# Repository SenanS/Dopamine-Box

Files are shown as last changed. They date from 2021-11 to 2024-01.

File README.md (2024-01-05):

# Dopamine-Box
## Blog post about the [Dopamine box here](https://senans.github.io/Technical-Blog/2023/10/04/Dopamine-Box/)

A flip switch circuit for encouraging you to complete tasks, loaded with lights and achievement sounds.

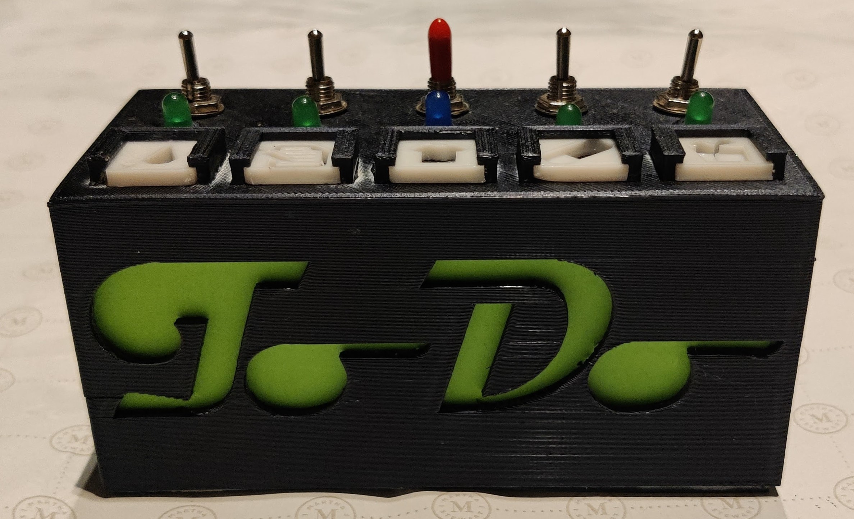
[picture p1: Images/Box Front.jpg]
The Dopamine Box


This project was conceptualized and designed by me, to gamify mundane tasks. It tracks up to five tasks, offering audiovisual feedback upon completion of each task, effectively rewarding the user with a dopamine hit.

[Board Schema](Schema.pdf) | [Stripboard Schema](Stripboard.pdf)
:-------------------------:|:-------------------------:
Schema | Stripboard

This project was more than just a tool for self-motivation; I used it as a springboard to dive into the realms of audio amplifiers and probability distributions.

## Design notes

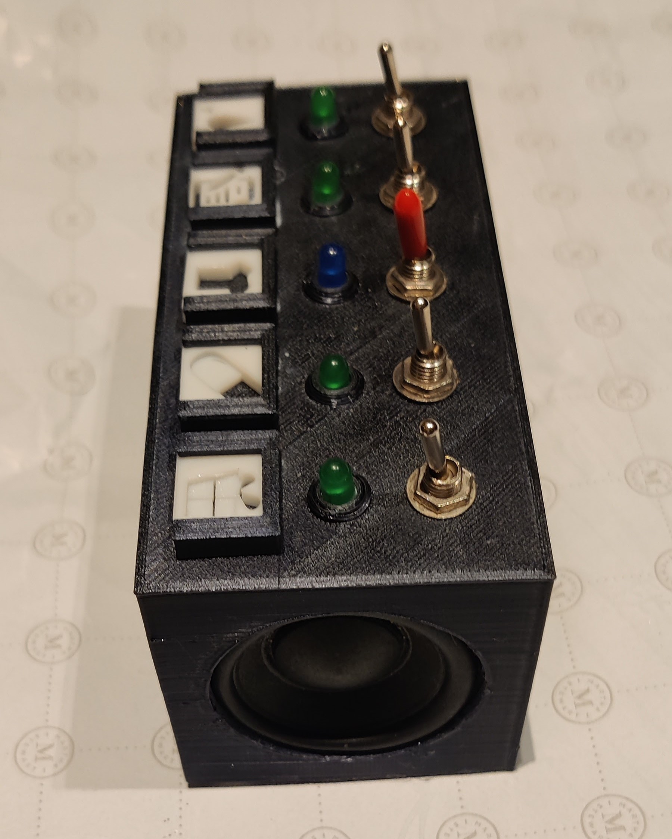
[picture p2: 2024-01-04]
Images/Box Side.jpg

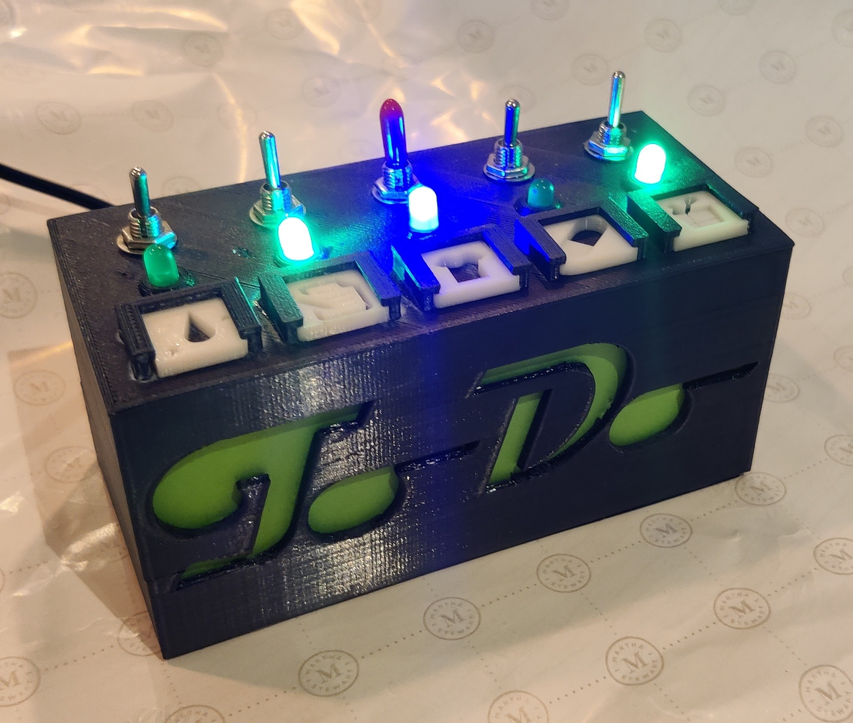
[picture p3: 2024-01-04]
Images/Box Lit.jpg

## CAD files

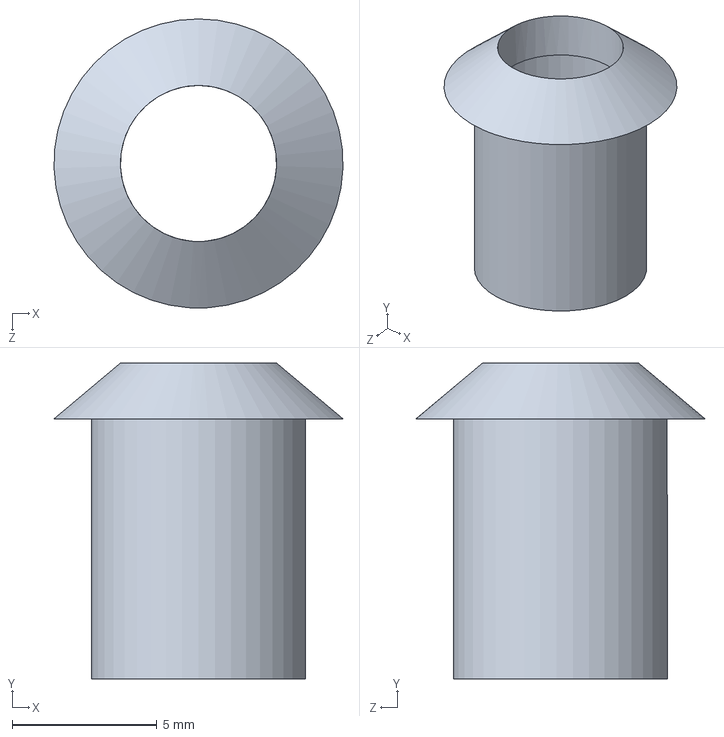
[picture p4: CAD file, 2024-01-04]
3D Models/LEDHolder.SLDPRT
9.99 x 10.9 x 10.0 mm

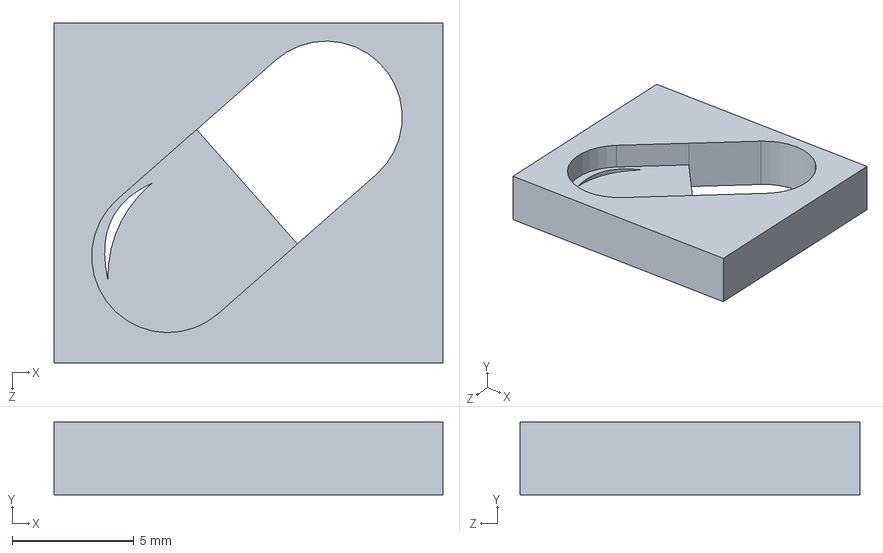
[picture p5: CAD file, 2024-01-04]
3D Models/Tokens/pill.SLDPRT
16.0 x 3.00 x 14.0 mm

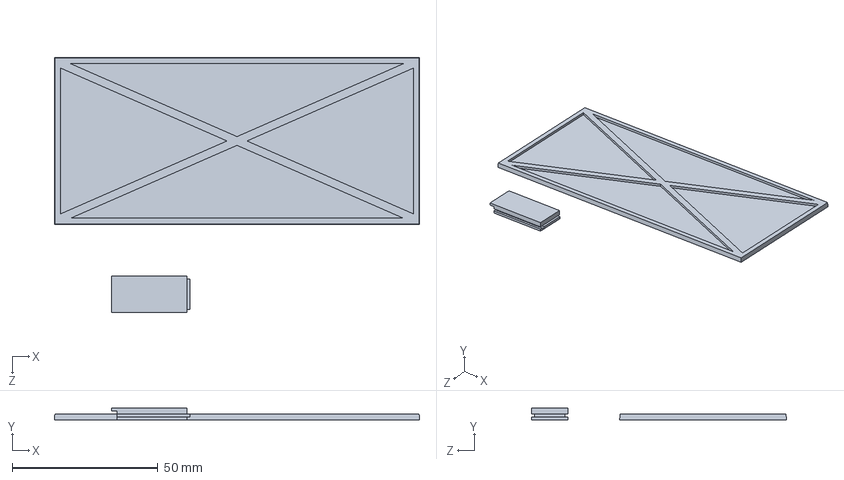
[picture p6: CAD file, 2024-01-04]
3D Models/Part2.SLDPRT
125.2 x 4.00 x 87.4 mm

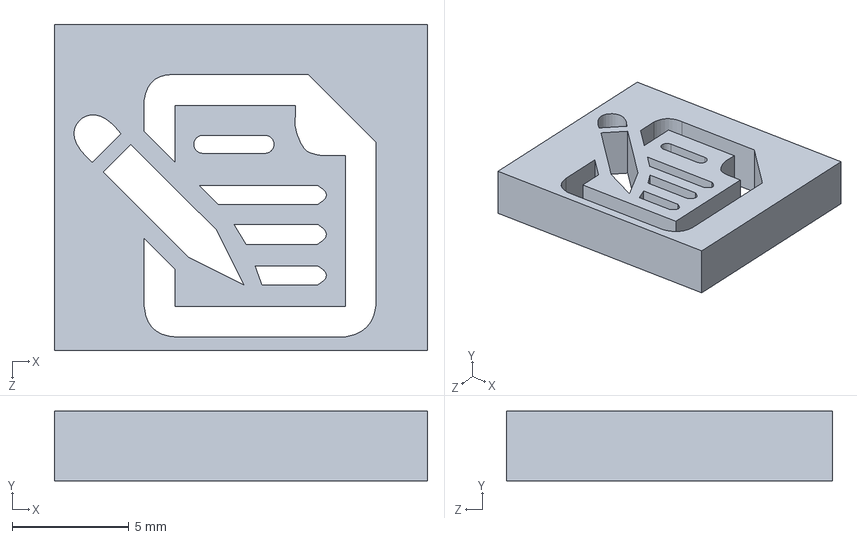
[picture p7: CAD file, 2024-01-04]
3D Models/Tokens/bits.SLDPRT
16.0 x 3.00 x 14.0 mm

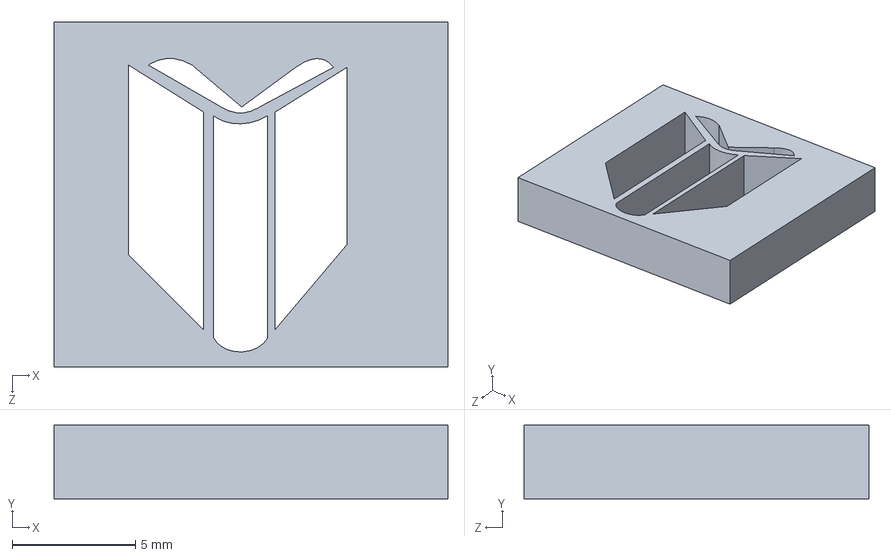
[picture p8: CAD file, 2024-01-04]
3D Models/Tokens/book.SLDPRT
16.0 x 3.00 x 14.0 mm

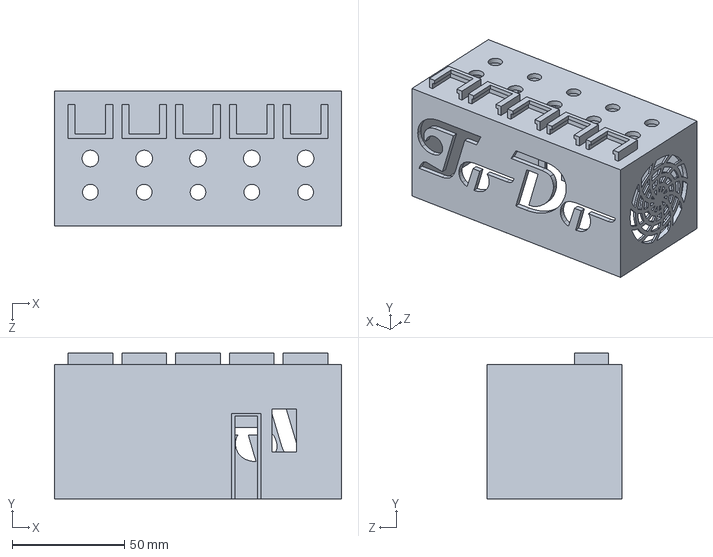
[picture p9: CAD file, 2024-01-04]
3D Models/Part1.SLDPRT
128.0 x 65.0 x 60.0 mm

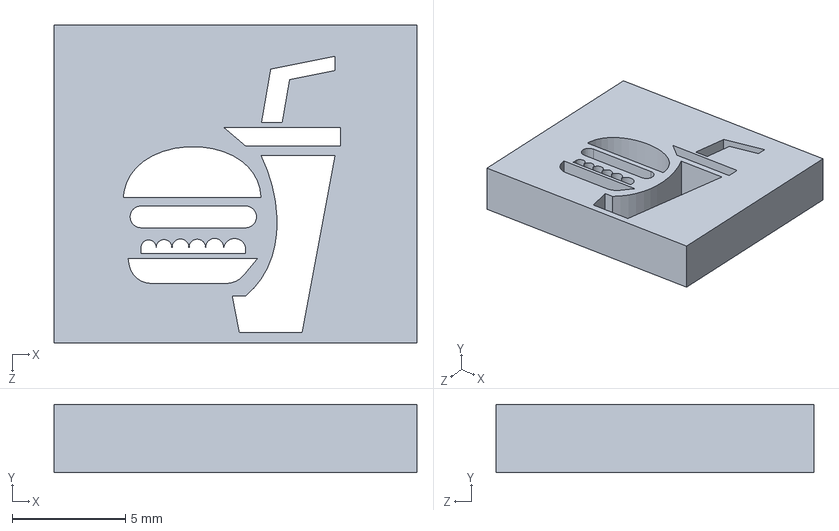
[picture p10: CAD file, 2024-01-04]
3D Models/Tokens/food.SLDPRT
16.0 x 3.00 x 14.0 mm

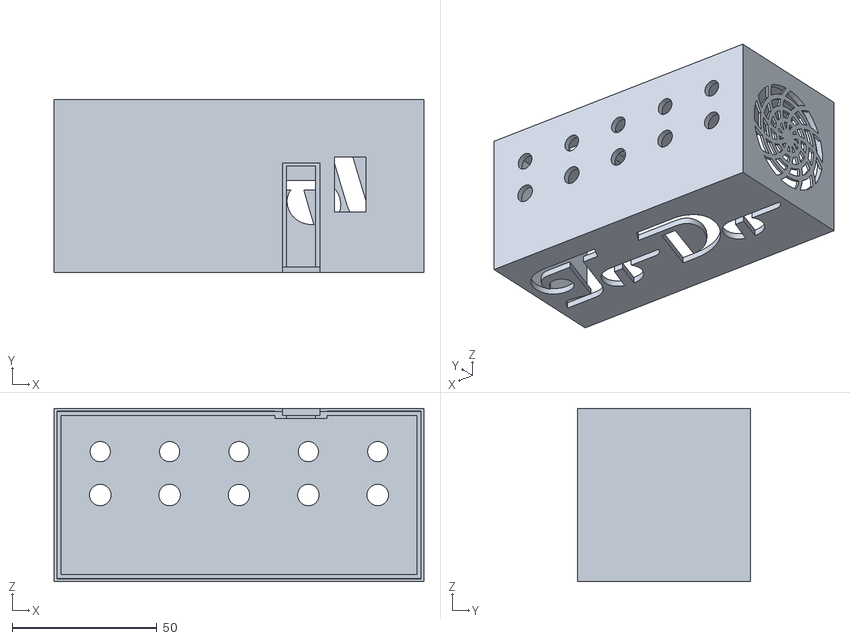
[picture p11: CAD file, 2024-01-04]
3D Models/dopbody.STL
128.0 x 60.0 x 60.0

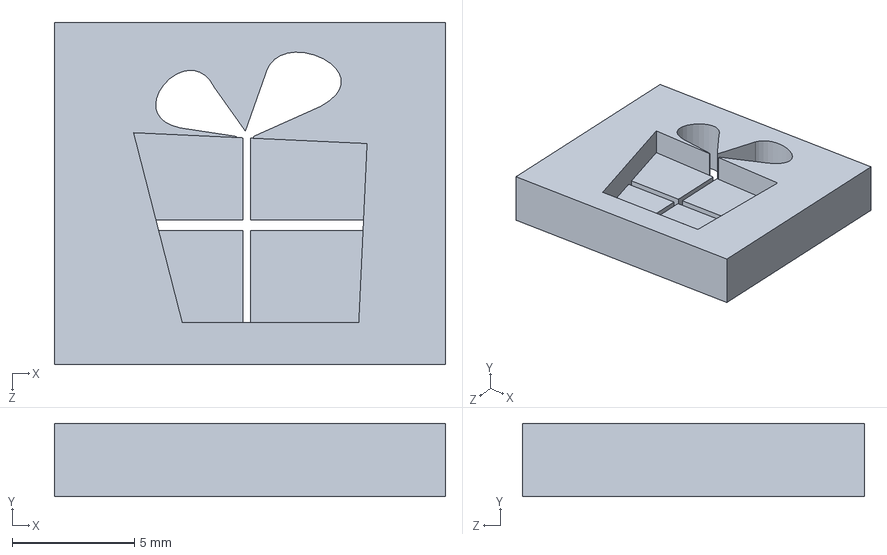
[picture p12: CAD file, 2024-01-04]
3D Models/Tokens/pressie.SLDPRT
16.0 x 3.00 x 14.0 mm

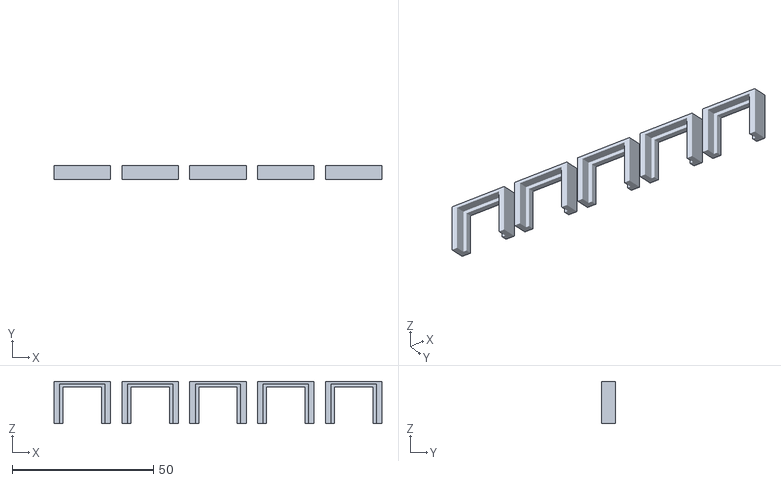
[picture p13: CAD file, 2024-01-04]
3D Models/dopHang.STL
116.0 x 5.00 x 15.0

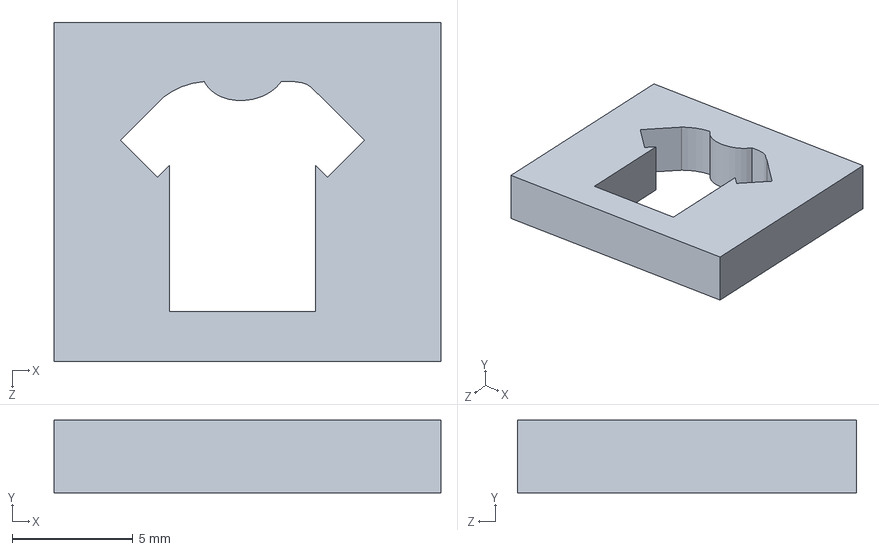
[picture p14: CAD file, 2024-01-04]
3D Models/Tokens/top.SLDPRT
16.0 x 3.00 x 14.0 mm

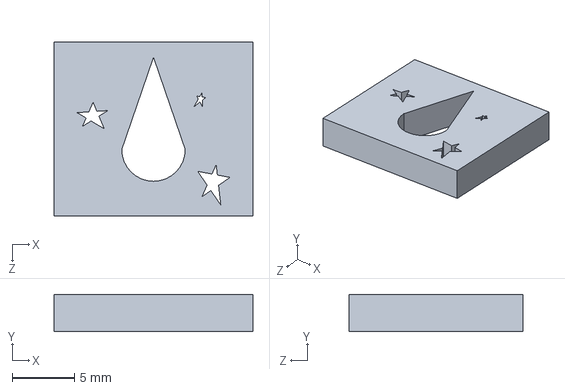
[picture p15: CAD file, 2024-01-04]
3D Models/Tokens/clean.SLDPRT
16.0 x 3.00 x 14.0 mm

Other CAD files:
3D Models/dopbase.STL
3D Models/LEDHolder.STL
3D Models/Tokens/bits.STL
3D Models/Tokens/book.STL
3D Models/Tokens/clean.STL
3D Models/Tokens/food.STL
3D Models/Tokens/pill.STL
3D Models/Tokens/pressie.STL
3D Models/Tokens/top.STL

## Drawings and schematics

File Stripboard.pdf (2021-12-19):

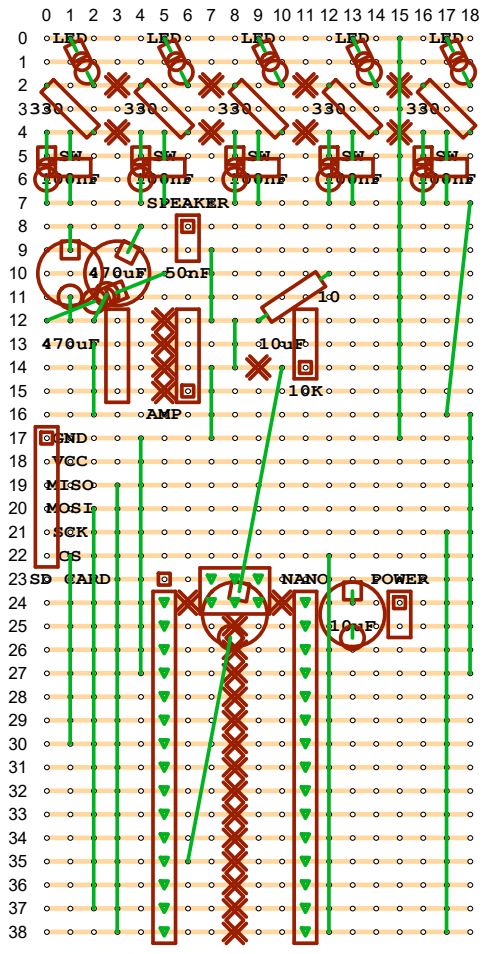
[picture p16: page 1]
AMP; LED; NANO; POWER; SPEAKER; SD CARD; GND; MISO MOSI SCK CS; VCC

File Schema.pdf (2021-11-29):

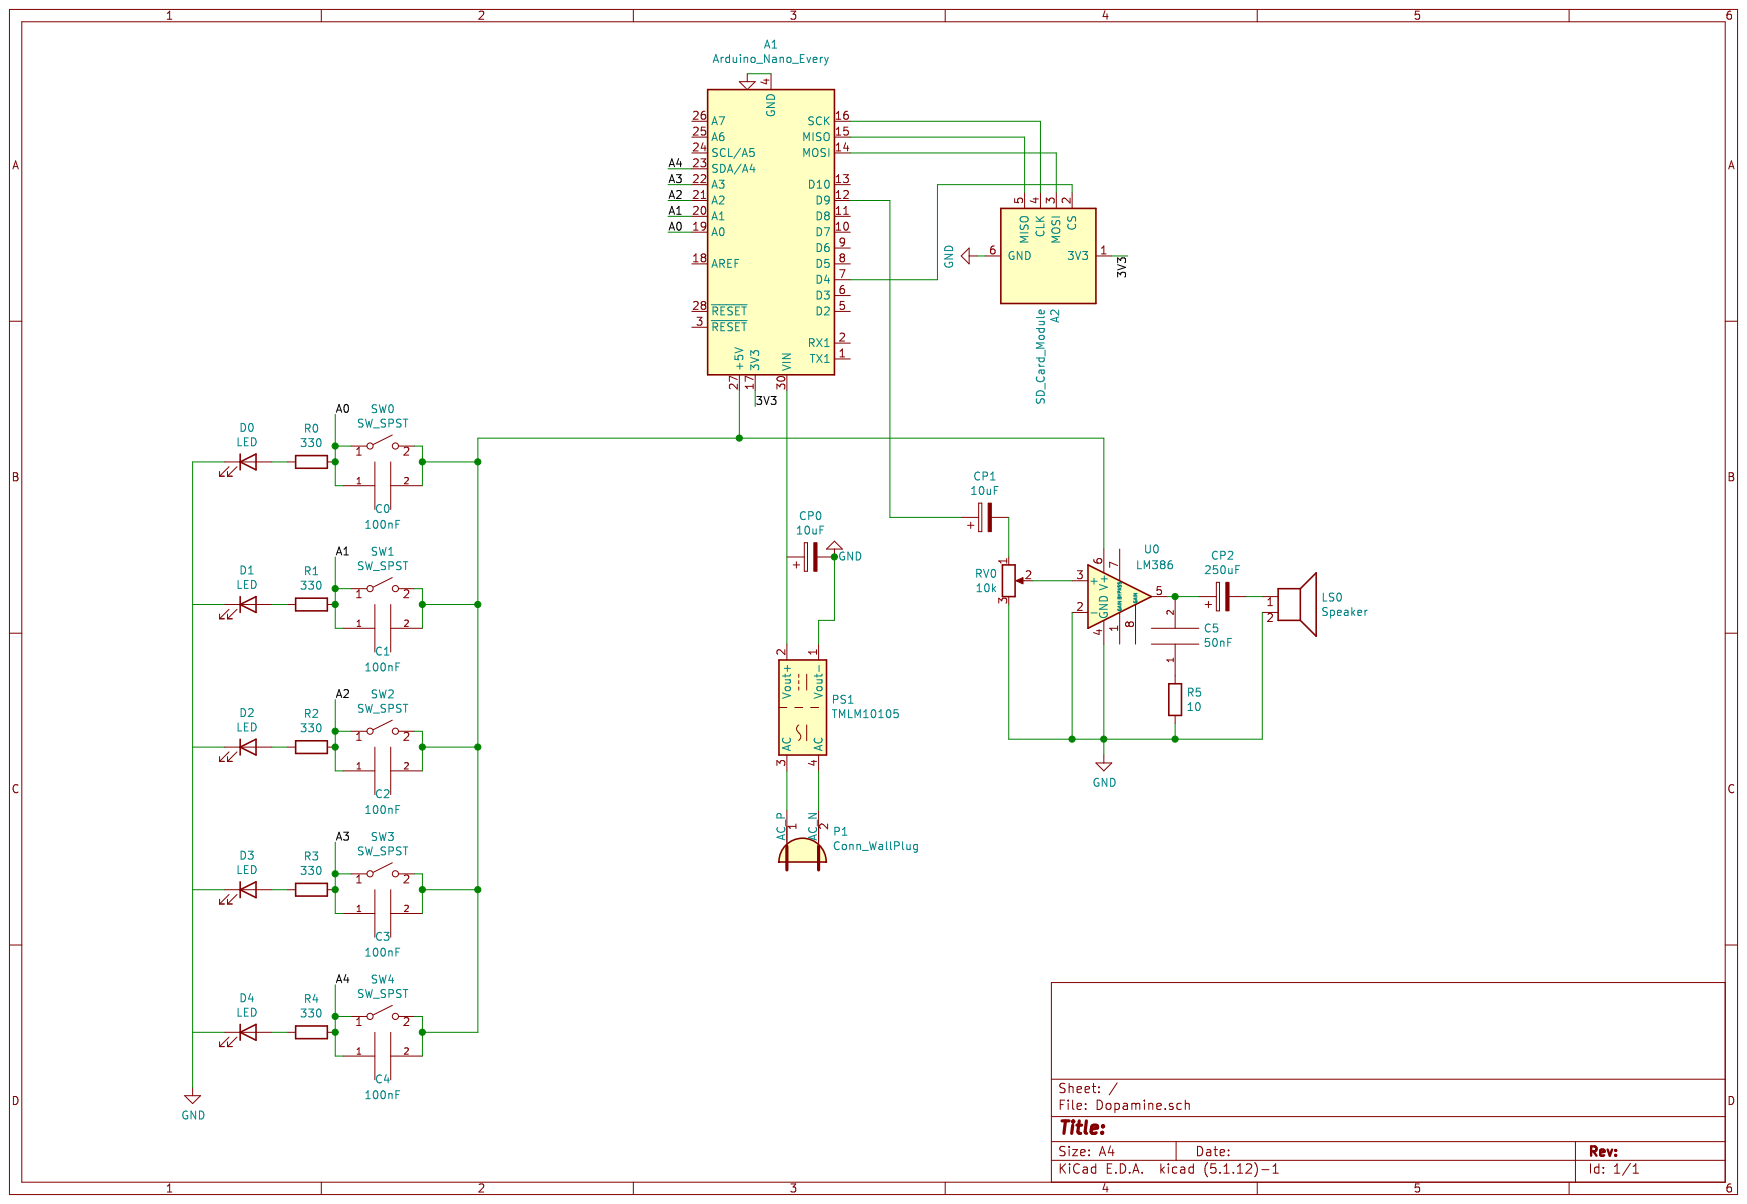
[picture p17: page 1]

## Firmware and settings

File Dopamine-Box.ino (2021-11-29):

#include "SD.h"
#include "TMRpcm.h"
#include "SPI.h"
//#include "LowPower.h"
#include <stdio.h>

// Analog Pins
#define sw0  A0             // 1st switch attached at pin A0
#define sw1  A1             // 2nd switch attached at pin A1
#define sw2  A2             // 3rd switch attached at pin A2
#define sw3  A4             // 4th switch attached at pin A3
#define sw4  A5             // 5th switch attached at pin A5

// Digital Pins
#define wakeUpPin 2         // Switch interrupt pin D2, for low power wakeup
#define SD_ChipSelectPin 4  // SD card chip select pin D4
#define speakerOut 9        // Speaker output pin D9
#define SD_MOSI 11          // SD card MOSI SPI output pin D11
#define SD_MISO 12          // SD card MISO SPI output pin D12
#define SD_SCK 13           // SD card SCK SPI output pin D13


// Variable to interface with the speaker & SD card
TMRpcm audioV;

// TODO: Remove
int counter = 6;

// Indicates the state of the system
//    There are 6 states from beginning to end. 0-->5, 
//    This mirrors the amount of switches flipped
int stateIndicator = 0, savedState, randomIndex;

// Probability of output:     A,    B,    C,    X,    F},
int outputProbability[5][5]={{80,   10,   7,    3,    0},
                             {30,   50,   15,   5,    0},
                             {5,    70,   22,   3,    0},
                             {0,    10,   85,   3,    2},
                             {0,    0,    0,    0,    100}
                            };
// Switch Inputs
int InputArray[] = {0, 0, 0, 0, 0};                            

// Arrays containing the filenames for each output sound effect
//    They are split into 5 categories, depending on rarity of occurrence.
//    The final category is for when all switches are flipped.
char *soundsA[] = {"a1.wav", "a2.wav", "a3.wav", "a4.wav", "a5.wav", "a6.wav", "a7.wav"};
char *soundsB[] = {"b1.wav", "b2.wav", "b3.wav", "b4.wav", "b5.wav"};
char *soundsC[] = {"c1.wav", "c3.wav"};
char *soundsX[] = {"x3.wav", "x2.wav", "x1.wav"};
char *soundsF[] = {"f0.wav", "f1.wav", "f2.wav", "f3.wav", "f4.wav", "f5.wav"};
int sizeSounds[] = {7, 5, 2, 3, 6};

void setup(){
  
//  Pin & Serial Setup
  Serial.begin(9600);
  pinMode(wakeUpPin, INPUT);
  pinMode(sw0, INPUT);
  pinMode(sw1, INPUT);
  pinMode(sw2, INPUT); 
  pinMode(sw3, INPUT);
  pinMode(sw4, INPUT);

//  SD Setup
  if (!SD.begin(SD_ChipSelectPin)) {
    Serial.println("SD fail");
    return;
  }
  else{
    Serial.println("SD OK");
  }

//  Audio library setup
  audioV.speakerPin = speakerOut;
  audioV.quality(1);
  audioV.setVolume(5);

//  Finite State Machine Setup
  savedState = stateIndicator;
}

void loop(){  
  
// Attach interrupt
//  attachInterrupt(digitalPinToInterrupt(wakeUpPin), readSwitchStates, RISING);
  
// Enter Sleep Mode
//  LowPower.powerDown(SLEEP_FOREVER, ADC_OFF, BOD_OFF); 

// Detach interrupt on interrupt
//  detachInterrupt(digitalPinToInterrupt(wakeUpPin)); 
  readSwitchStates();

//   Check State
  if (savedState < stateIndicator){
//    Update LEDs    
//    Create sounds on advancement
    Serial.println(stateIndicator);
    playRandomSound(stateIndicator);
  }
  
// Perform Operations

// Update State
  savedState = stateIndicator;

  
//  debugBySerial();
}

void playRandomSound(int state){

  randomIndex = checkProbability(random(1, 101), state, 0);
//  randomIndex = state - 1;
  Serial.print("randomIndex = ");
  Serial.println(randomIndex);
 
  if(randomIndex == 4){
    audioV.play(soundsF[random(0, sizeSounds[4])]);
  }
  else if(randomIndex == 3){
    audioV.play(soundsX[random(0, sizeSounds[3])]);
  }
  else if(randomIndex == 2){
    audioV.play(soundsC[random(0, sizeSounds[2])]);
  }
  else if(randomIndex == 1){
    audioV.play(soundsB[random(0, sizeSounds[1])]);
  }
  else{
    audioV.play(soundsA[random(0, sizeSounds[0])]);
  }
  
}

// Subtractive & Recursive function to implement a probability distribution on a number between 1-100
int checkProbability(int randomStop, int distIndex, int probIndex){
  
  int comparison = randomStop - outputProbability[distIndex - 1][probIndex];
  
  char str[32];
  sprintf(str, "Orig: %3d Comp: %3d Index: %3d", randomStop, comparison, probIndex, distIndex);
  Serial.println(str);
  
  if(comparison >= 1){
    return checkProbability(comparison, distIndex, probIndex + 1);
  }
  else{
    return probIndex;
  }
}


// Reads the switches and counts the amount in the on state.
void readSwitchStates(){

  InputArray[0] = digitalRead(sw0);
  InputArray[1] = digitalRead(sw1);
  InputArray[2] = digitalRead(sw2);
  InputArray[3] = digitalRead(sw3);
  InputArray[4] = digitalRead(sw4);
  
  debugPrintState();

  stateIndicator = InputArray[0] + InputArray[1] + InputArray[2] + InputArray[3] + InputArray[4];
}

void debugBySerial(){
  // Use the Serial connection to test outputs or simulate inputs
  
  if(Serial.available()){    
    switch(Serial.read()){
      case '0': audioV.play("f0.wav"); Serial.println("f0-cool"); break;
      case '1': audioV.play("f1.wav"); Serial.println("f1-cool"); break;
      case '2': audioV.play("f2.wav"); Serial.println("f2-cool"); break;
      case '3': audioV.play("f3.wav"); Serial.println("f3-cool"); break;
      case '4': audioV.play("f4.wav"); Serial.println("f4-cool"); break;
      case '5': audioV.play("f5.wav"); Serial.println("f5-cool"); break;
      case 'z': audioV.play("z.wav"); Serial.println("zelda-cool"); break;
      case 'l': audioV.play(soundsA[counter]); Serial.println(counter--); break;
      case 'P': audioV.play("temple"); break;
      case 't': audioV.play("catfish"); break;
      case 'p': audioV.pause(); break;
      case '?': if(audioV.isPlaying()){ Serial.println("A wav file is being played");} break;
      case 'S': audioV.stopPlayback(); break;
      case '[': stateIndicator--; break;
      case ']': stateIndicator++; break;
      case '=': audioV.volume(1); break;
      case '-': audioV.volume(0); break;
      default: break;
    }
  }
}

void debugPrintState(){
  // Print formatted input state to serial
  
  if(Serial.available()){    
    char str[32];
    sprintf(str, "%4d   %4d   %4d   %4d   %4d", InputArray[0], InputArray[1], InputArray[2], InputArray[3], InputArray[4]);
    Serial.println(str);
  }
}

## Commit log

2021-06-14 Skeleton code written for interrupts, low power & FSM
2021-06-17 Working Speaker & Switch FSM System
2021-11-29 Added Schematic
2024-01-04 Project dusting & polishing
    [LEDHolder.SLDPRT, LEDHolder.STL, Part1.SLDPRT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]
